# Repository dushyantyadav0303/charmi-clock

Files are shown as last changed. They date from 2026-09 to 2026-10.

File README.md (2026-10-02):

<h1 align="center">
  <br>
  

</h1>
<div align="center"> 



</div>

<h4 align="center">

Charmi Clock 



</h4>
<div align="center">





</div>
<p align="center">
  <a href="#about-the-project">About</a> •
  <a href="# why-i-made-this?">Motivation</a> •
  <a href="#repository-structure">Structure</a> •
  <a href="#cad">CAD</a> •
  <a href="#Render">Render</a> •
   <a href="#bill-of-materials">BOM</a> •
  <a href="#Production">Production</a> •
  <a href="#license">License</a> •
  <a href="#credits">Credits</a>
</p>

<br>
<br>

<div align="center">


</div>

<br>

> [!NOTE]
> # Sorry, I'm unable to fully print it in real life because I've run out of filament in between of print.

## printable like: https://www.printables.com/model/1854367-charmi-clock
## About the Project
### **Charmi Clock** - it is fully working 3d printable cuckoo clock design in fusion 360. it having small mechanical bird that make cuckoo sound every hour.
## why i made this?
### While Doom Scrolling I saw a Traditional Cuckoo clock and the next Second I love this Clock. But it is not available in India!!!. So I Think why not to 3D printed but there isn't 3D model available on Internet. So I thought why not to make our own. And make it open source so everyone can enjoy this cuckoo clock.

## Repository Structure
- `src/` - project sources
- `production/` - Production File
- ` Firmware/` - Firmware code file

## CAD 
<div align="center">
 

 </div>

- source: `src/`  

## Render
<div align="center">
 

 </div>

## Connection diagram
<div align="center">
 

 </div>

## Bill of Materials
Source: `BOM.csv`

|item |Qantity|price|link to buy |
|---|---|-----|---|
|Pla+ filament| 1320gram| 11$ |https://india.numakers.com/products/pla-filament|
|Quartz Clock Movement Machine| 1 Pcs| 2$ |https://amzn.in/d/02pkLzRc|
| MG90S Servo motor| 1 Pcs | 1.3$ |https://robu.in/product/towerpro-mg90s-mini-digital-servo-motor-180-rotation-standard-quality|
|Esp32 Devboard| 1 Pcs| 5$ |https://robu.in/product/esp-wroom-32-wifi-bluetooth-networking-smart-component-development-board/|
|MP3-TF-16P MP3 SD Card Module | 1 Pcs| 1$ |https://robu.in/product/mp3-tf-16p-mp3-disk-tf-card-module-serial-port/|
|Sd card| 1 Pcs| 3$ |https://amzn.in/d/09BRnbRF|
|Speaker| 1 Pcs| 0.4$ |https://robu.in/product/0-5w-8ohm-trumpet-speaker-diameter-28mm/|
|Total |  | 23.7$  ||

## Production

<div align="center">
 


 </div>

### Recommended Print Specifications

| Specification | Default Value / Range |
| :--- | :--- |
| **Printer Nozzle** | 0.4 mm Stainless Steel |
| **Layer Height** | 0.2 mm |
| **First Layer Height** | 0.2 mm |
| **Nozzle Temperature** | Depends on your Filament |
| **Build Plate Temperature** | Depends on your Filament |
| **Sparse Infill Density** | 10% |
| **Max Toolhead Speed** | 500 mm/s |
| **Max Acceleration** | 8000 mm/s² |
| **Support** | tree 25° |

 source: `Production`

## License
This project is licensed under the **MIT License** - see the [LICENSE](LICENSE) file for details.

## Credits
<div align="center">


 
 

</div>

This project was created during a [Hack Club](https://hackclub.com) event [Live](https://live.hackclub.com).
- **[Fusion 360](https://www.autodesk.com/products/fusion-360)** - Cad Designing
- **[Blender](https://www.blender.org)** - Render
- **[Bambu Studio](https://bambulab.com/en/download/studio)** - Slicing the Model

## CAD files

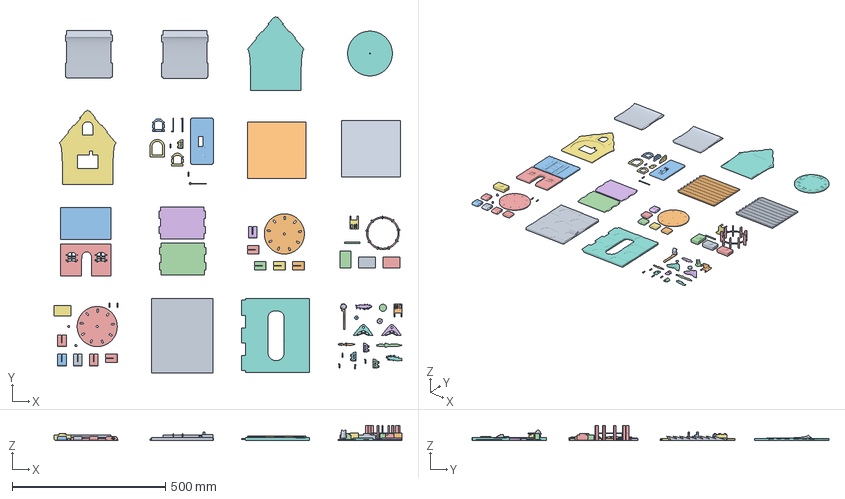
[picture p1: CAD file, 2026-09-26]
Production/charmi-clock.3mf
1134.8 x 1162.6 x 48.0 mm
main (1) (1)
chair
servo-holder
table
door-R
base
door-L
needle
base (4)
windo 2 grass
Door-frame
windo 1 grass
base (3)
needle (1)
windo 1
windo 2
base (2)
windo 1 (2)
chair (1)
windo 2 (3)
needle (2)
windo 2 (4)
windo 1 (4)
windo 2 (2)
windo 2 (1)
main
windo 1 (1)
main (1) (1) (1)
windo 1 (3)
main (1)
clock
roof-L
roof-R
gate
side2
side3
side4
base (1)
base (5)
bird 2

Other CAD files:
Production/charmi-clock.stl
src/charmi-clock.f3d

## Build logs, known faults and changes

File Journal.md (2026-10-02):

---
title: "Charmi Clock"
description: "it is fully working 3d printable cuckoo clock design in fusion 360. it having small mechanical bird that make cuckoo sound every hour."
Startes_at: "2026-09-15"
---



## Hackatime link: https://hackatime.hackclub.com/@dushyantYadav0303/project/Clock

# From 2026-09-15 to  2026-09-21            Clock CAD
## lapse: https://lapse.hackclub.com/timelapse/PW_10r9PF2CH
## lapse: https://lapse.hackclub.com/timelapse/WTPi0WL1P2zL
## lapse: https://lapse.hackclub.com/timelapse/SjA6OFzC7JId
### Hi there,
#### this project Cad is the most learning project. I learn too many things in fusion 360. Like making hinges, Doors, Different type of modes: (Assembly, part,Hybrid) , 
making with Components, Learning Different type of joints and joint features. 
#### also It is not easy for me to make the hinge for door. I get fail three time. Before getting the proper Hinge for door.
#### Also many thing is not capture in lapses. Like testing, Debugging model, Assembly and much more. But it is okay I'm happy that I learn a lot of things. 
#### In this lapse I'm making the cad model of cuckoo clock in fusion 360 + bird in blender. And all the journey of my learning.




---

# 2026-09-22       Optimising the 3D model and making it printable
## lapse: https://lapse.hackclub.com/timelapse/E5zXpUQuVpq9
### yoo gng,
#### So today I did the most important work. **Making it printable** So in this part I cut down the things and split them into small object. So it is easy to print and easy to assemble. 
#### then I'm optimising the model at the same time. In which I am ensuring that the every part have the Strength required not overkill. and also Take less filament. for Comparison the model taking over 2 times filament before Optimising it. 




---

# 2026-09-23             Writing the firmware
## lapse: https://lapse.hackclub.com/timelapse/Fc7wk9E5ua-q
## lapse: https://lapse.hackclub.com/timelapse/2VMl2lRMlDxn
### ni heo,
#### today, I'm making the making the firmware for clock Bird mechanism + audio system. So basic Esp32 connnect with wifi and sync the time and every hour it run a Function. 
In which the bird have to come out play the cuku-cuku sound and return back.

   <br>

---

# 2026-10-03             Open sourcing the project
## Lapse: https://lapse.hackclub.com/timelapse/V_U9r_hyQswo
### Hola,
#### So today i complete the repo and printable page and make it Public for everyone. inc: Circuit diagram,  3D model and Journal the whole process.

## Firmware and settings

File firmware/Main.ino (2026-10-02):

#include <WiFi.h>
#include <time.h>
#include <ESP32Servo.h>
#include "HardwareSerial.h"
#include "DFRobotDFPlayerMini.h"




const char* ssid = "dushyant";
const char* pass = "12345678";+
const char* ntpServer = "pool.ntp.org";


const long gmtOffset_sec = 5 * 3600 + 30 * 60;
const int   daylightOffset_sec = 0;



const byte RXD2 = 16; 
const byte TXD2 = 17;
HardwareSerial dfSD(2);
DFRobotDFPlayerMini player;




#define BOOT_PIN 0
int lastHour = -1;



void printLocalTime()
{
  struct tm timeinfo;
  if(!getLocalTime(&timeinfo)){
    Serial.println("Failed to obtain time");
    return;
  }
  Serial.println(&timeinfo, "%H:%M:%S");
}




Servo myServo;
const int SERVO_PIN = 13;


void setup(){
  Serial.begin(115200);
   pinMode(BOOT_PIN, INPUT_PULLUP);
  myServo.attach(SERVO_PIN);
  WiFi.mode(WIFI_STA);
  myServo.write(0);
  delay(1500);
   myServo.detach();
  WiFi.disconnect();
  delay(100);
  
  WiFi.begin(ssid, pass);
  Serial.print("Connecting to ");
  Serial.println(ssid);

  while (WiFi.status() != WL_CONNECTED) {
    delay(500);
    Serial.print(".");
  }

  Serial.println("connected!!!");
   configTime(gmtOffset_sec, daylightOffset_sec, ntpServer);
  printLocalTime();


  dfSD.begin(9600, SERIAL_8N1, RXD2, TXD2);
  delay(1500);

  if (player.begin(dfSD)) 
  {
    Serial.println("OK");
    player.volume(30); 
  } 
  else 
  {
    Serial.println("Connecting to DFPlayer failed!");
  }


}

 


void loop()
{
  struct tm timeinfo;
  if (!getLocalTime(&timeinfo)) {
    return;
  }

  Serial.println(&timeinfo, "%H:%M:%S");
  if (timeinfo.tm_min == 0 && timeinfo.tm_hour != lastHour) {
    lastHour = timeinfo.tm_hour;
    everyhour();
  }

  if (digitalRead(BOOT_PIN) == LOW) {
    everyhour();
  }
  delay(1000);
}


void everyhour(){
      Serial.println("hour hits");
        Serial.println("Servo attached");
    myServo.attach(SERVO_PIN);
    Serial.println("moving servo out");
      myServo.write(180);
       player.play(1);
      delay(5000);
       Serial.println("moving servo in");
      myServo.write(0);
       delay(10000);
         myServo.detach();
       Serial.println("moving detached");

}

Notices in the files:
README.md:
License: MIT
